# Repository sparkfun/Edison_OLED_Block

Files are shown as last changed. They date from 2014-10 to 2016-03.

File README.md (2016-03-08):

SparkFun Edison OLED Block
===========================

SparkFun Edison OLED Block

[*SparkFun Edison OLED Block(DEV-13035)*](https://www.sparkfun.com/products/13035)

Equip your Edison with a graphic display using the Edison OLED board! This board features a 0.66", 64x48 pixel monochrome OLED.

To add some control over your Edison and the OLED, this board also includes a small joystick and a pair of push-buttons. Use them to create a game, file navigator, or more!

Repository Contents
-------------------
* **/Firmware** - Example Pong sketch to demonstrate OLED Functionality. 
* **/Hardware** - All Eagle design files (.brd, .sch)
* **/Production** - Test bed files and production panel files

Documentation
--------------
* **[Hookup Guide](https://learn.sparkfun.com/tutorials/sparkfun-blocks-for-intel-edison---oled-block)** - Basic hookup guide for the OLED Block.
* **[SparkFun Fritzing repo](https://github.com/sparkfun/Fritzing_Parts)** - Fritzing diagrams for SparkFun products.
* **[SparkFun 3D Model repo](https://github.com/sparkfun/3D_Models)** - 3D models of SparkFun products. 
* **[SparkFun Graphical Datasheets](https://github.com/sparkfun/Graphical_Datasheets)** -Graphical Datasheets for various SparkFun products.

License Information
-------------------

This product is _**open source**_! 

Please review the LICENSE.md file for license information. 

If you have any questions or concerns on licensing, please contact techsupport@sparkfun.com.

Distributed as-is; no warranty is given.

- Your friends at SparkFun.

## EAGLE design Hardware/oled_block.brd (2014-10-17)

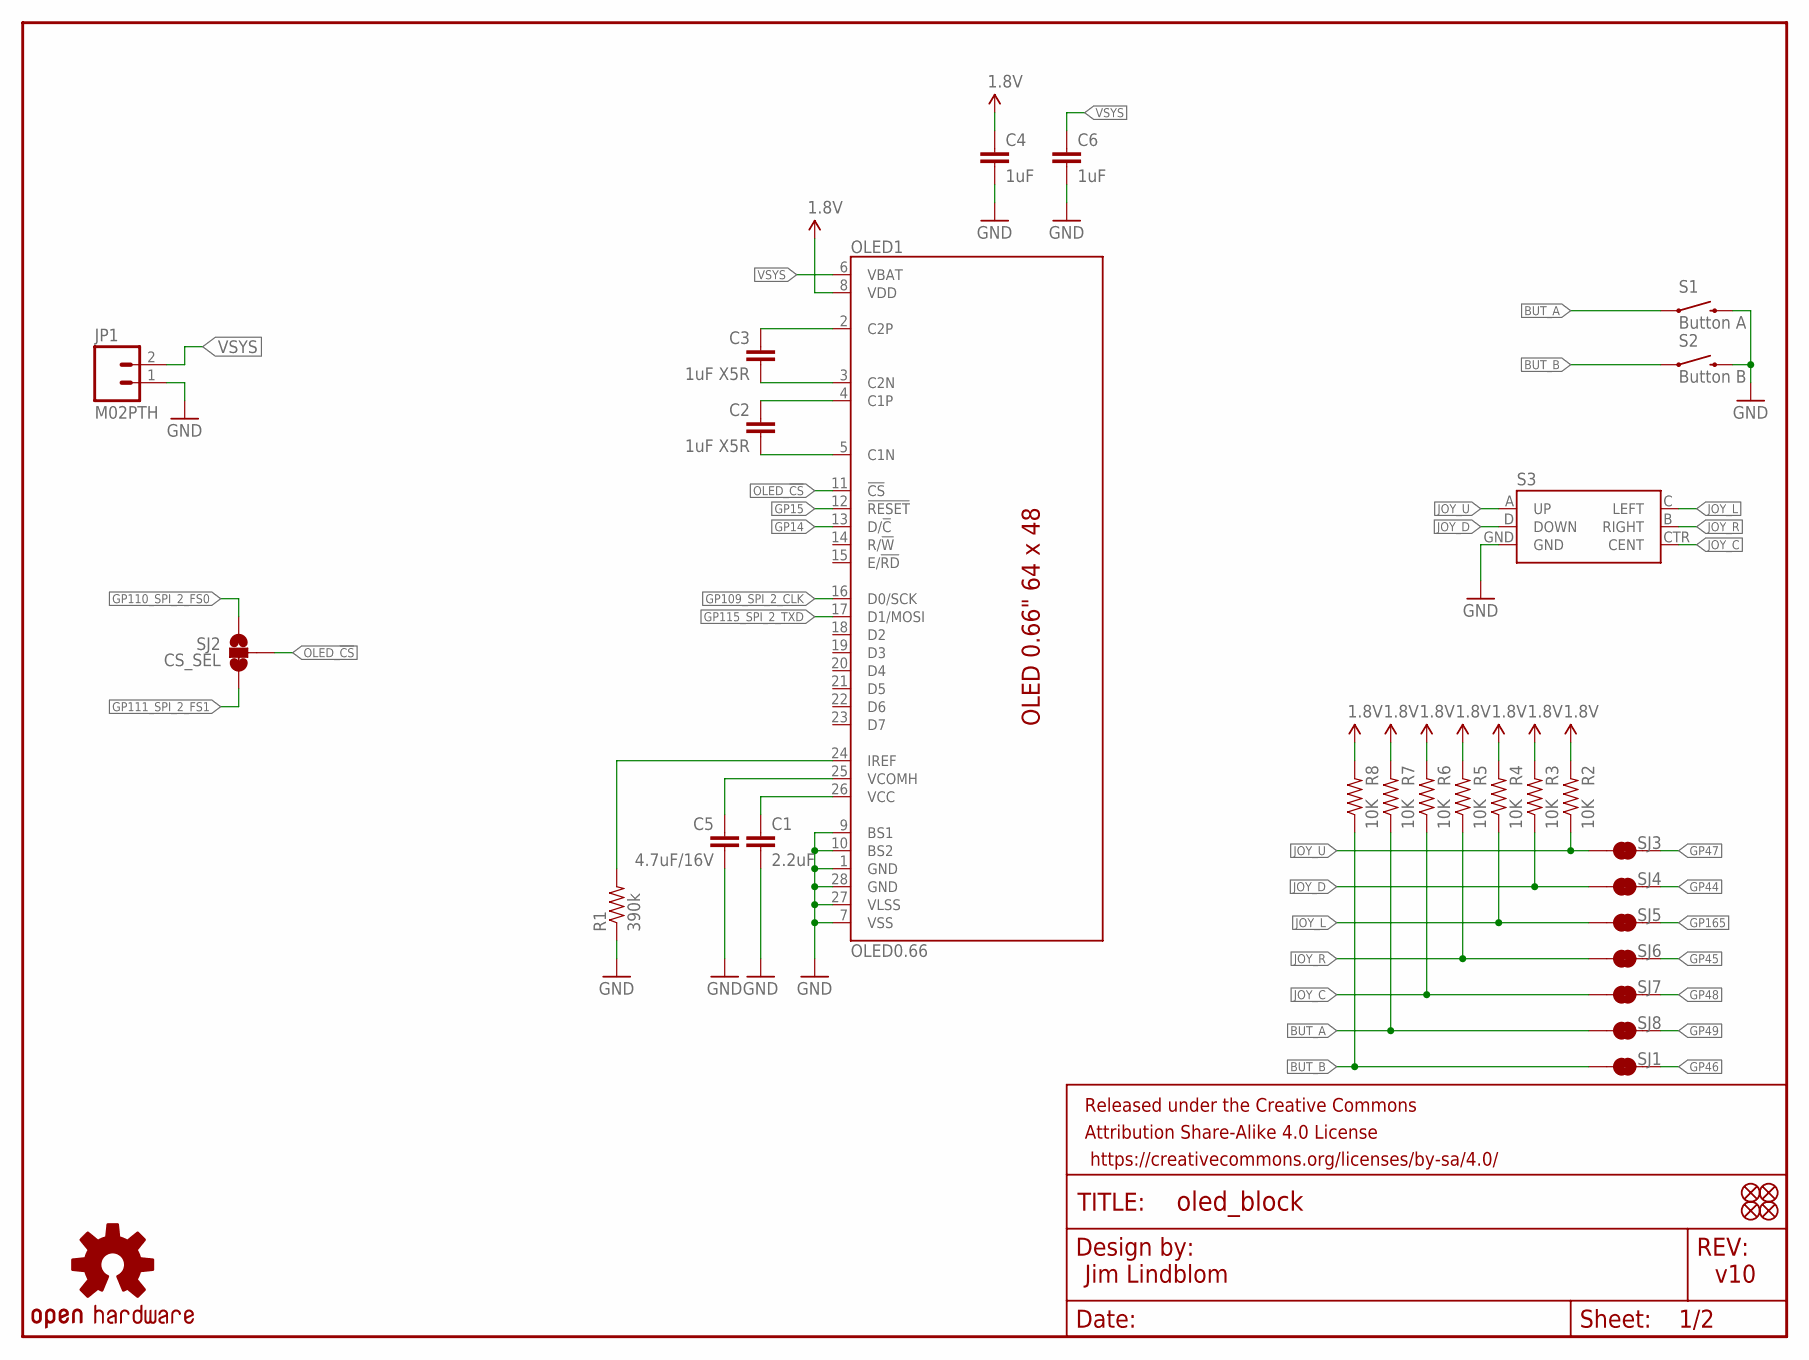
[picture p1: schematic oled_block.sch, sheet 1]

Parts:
C1: 2.2uF; 0805
C2, C3: 1uF X5R; 0805
C4, C6: 1uF; 0603-CAP
C5: 4.7uF/16V; 1206
FID1, FID2, FID3, FID4: FIDUCIAL1X2; FIDUCIAL-1X2
FRAME1: FRAME-LETTER; CREATIVE_COMMONS
JP1: M02PTH; 1X02
LOGO2: OSHW-LOGOS; OSHW-LOGO-S
OLED1: OLED0.66; OLED-0.66-64X48
R1: 390k; 0603-RES
R2, R3, R4, R5, R6, R7, R8: 10K; 0603-RES
S1: Button A; TACTILE_SWITCH_TALL
S2: Button B; TACTILE_SWITCH_TALL
S3: JOYSTICK_MINI
SJ1, SJ3, SJ4, SJ5, SJ6, SJ7, SJ8: JUMPER-PAD-2-NC_BY_TRACE; PAD-JUMPER-2-NC_BY_TRACE_YES_SILK
SJ2: CS_SEL; PAD-JUMPER-3-2OF3_NC_BY_TRACE_YES_SILK_FULL_BOX

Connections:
1.8V: C4.1, OLED1.8 (VDD), R2.2, R3.2, R4.2, R5.2, R6.2, R7.2, R8.2; also elsewhere on the board
BUT_A: R7.1, S1.A2 (1), SJ8.1
BUT_B: R8.1, S2.A2 (1), SJ1.1
C1N: C2.2, OLED1.5 (C1N)
C1P: C2.1, OLED1.4 (C1P)
C2N: C3.2, OLED1.3 (C2N)
C2P: C3.1, OLED1.2 (C2P)
GND: C1.2, C4.2, C5.2, C6.2, JP1.1, OLED1.1 (GND), OLED1.7 (VSS), OLED1.9 (BS1), OLED1.10 (BS2), OLED1.27 (VLSS), OLED1.28 (GND), R1.1, S1.B2 (2), S2.B2 (2), S3.GND; also elsewhere on the board
GP14: OLED1.13 (D/!C!); also elsewhere on the board
GP15: OLED1.12 (!RESET!); also elsewhere on the board
GP44: SJ4.2; also elsewhere on the board
GP45: SJ6.2; also elsewhere on the board
GP46: SJ1.2; also elsewhere on the board
GP47: SJ3.2; also elsewhere on the board
GP48: SJ7.2; also elsewhere on the board
GP49: SJ8.2; also elsewhere on the board
GP109_SPI_2_CLK: OLED1.16 (D0/SCK); also elsewhere on the board
GP110_SPI_2_FS0: SJ2.1; also elsewhere on the board
GP111_SPI_2_FS1: SJ2.3; also elsewhere on the board
GP115_SPI_2_TXD: OLED1.17 (D1/MOSI); also elsewhere on the board
GP165: SJ5.2; also elsewhere on the board
IREF: OLED1.24 (IREF), R1.2
JOY_C: R6.1, S3.CTR (CENT), SJ7.1
JOY_D: R3.1, S3.D (DOWN), SJ4.1
JOY_L: R4.1, S3.C (LEFT), SJ5.1
JOY_R: R5.1, S3.B (RIGHT), SJ6.1
JOY_U: R2.1, S3.A (UP), SJ3.1
OLED_!CS!: OLED1.11 (!CS!), SJ2.2
VCC: C1.1, OLED1.26 (VCC)
VCOMH: C5.1, OLED1.25 (VCOMH)
VSYS: C6.1, JP1.2, OLED1.6 (VBAT); also elsewhere on the board

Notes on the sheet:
Jim Lindblom
v10

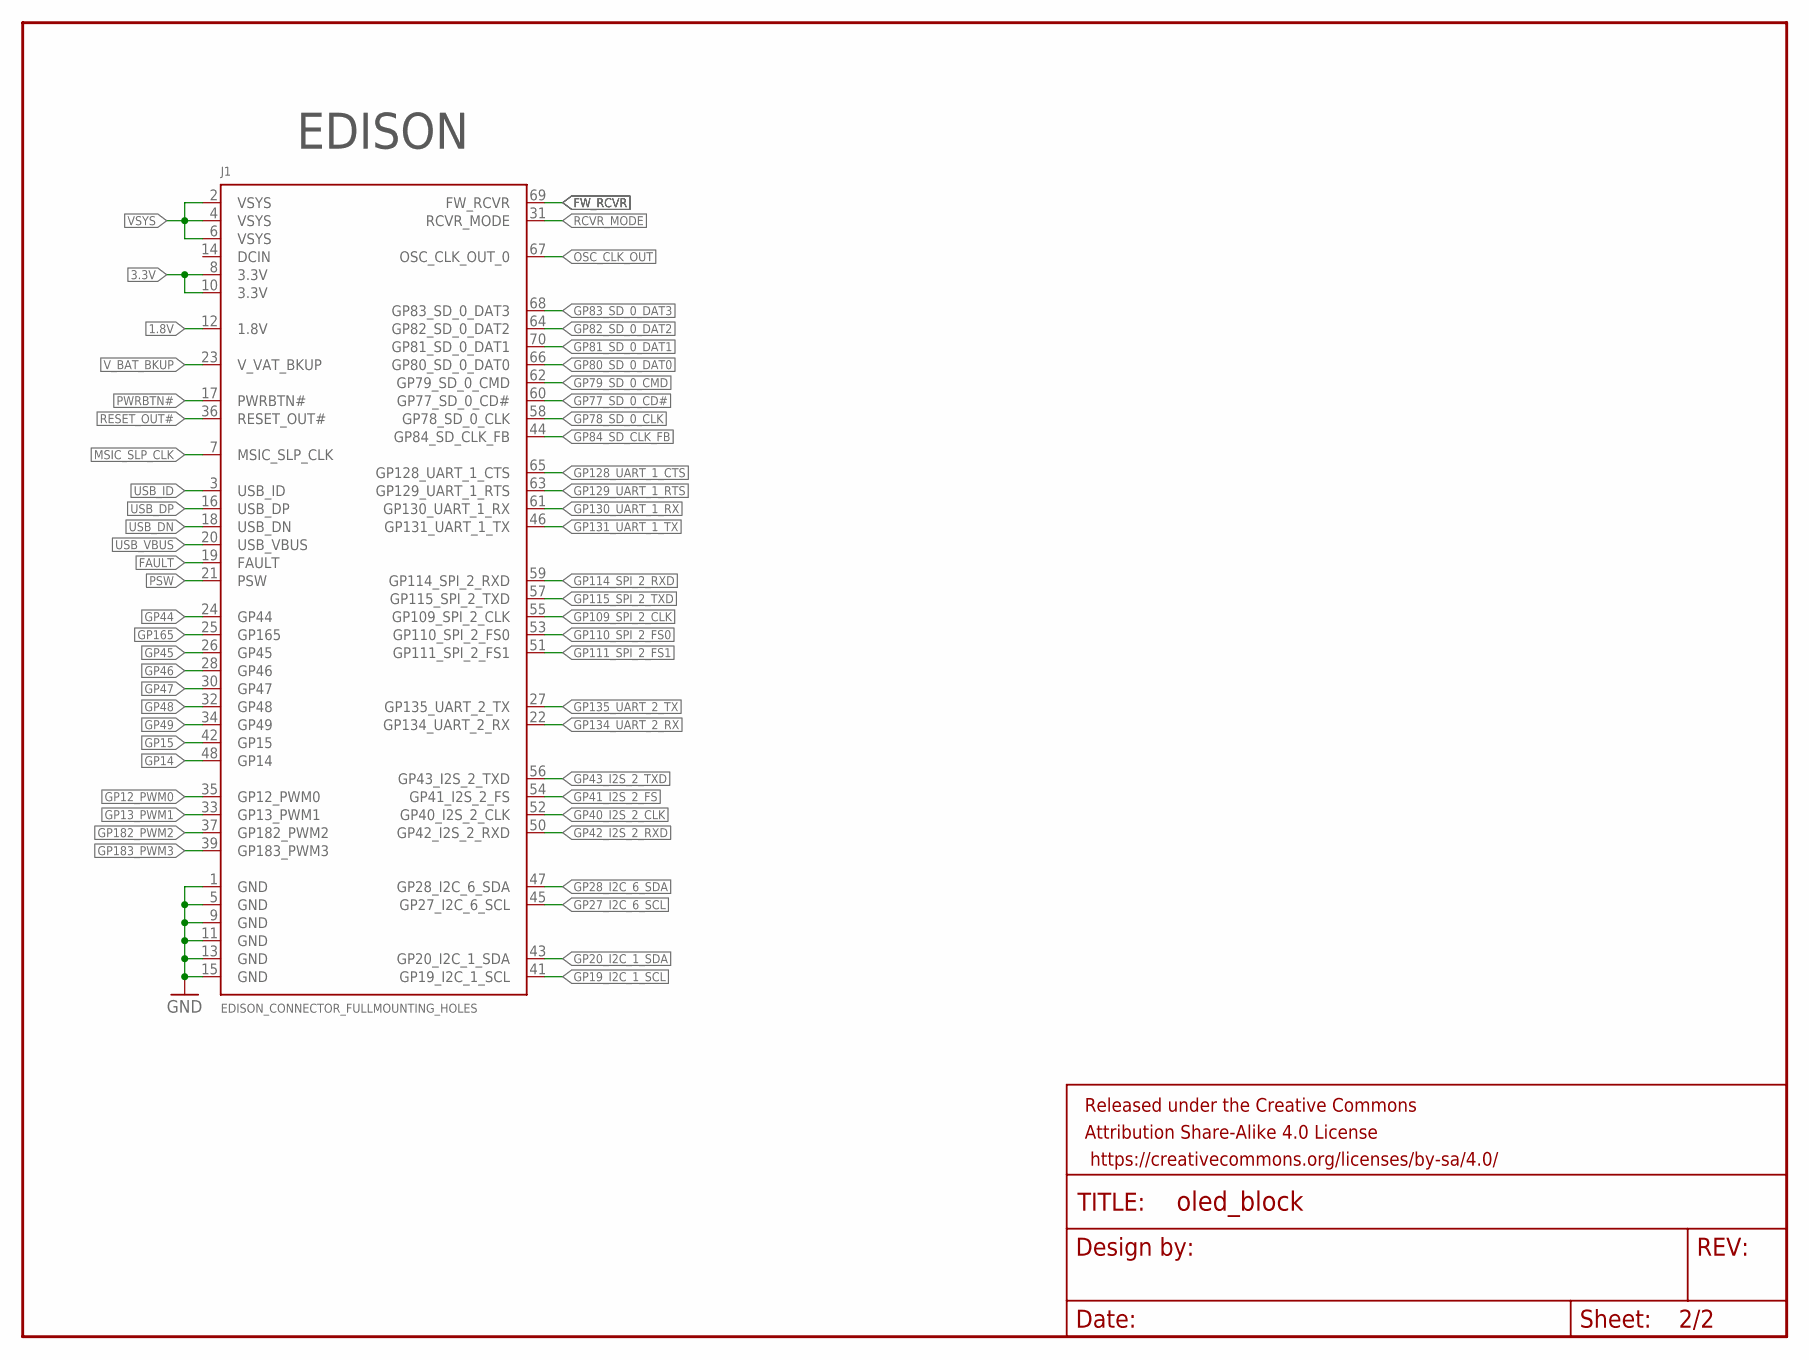
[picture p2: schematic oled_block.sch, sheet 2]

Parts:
FRAME2: FRAME-LETTER; CREATIVE_COMMONS
J1: EDISON_CONNECTOR_FULLMOUNTING_HOLES; EDISON_DAUGHTER

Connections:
1.8V: J1.12 (1.8V); also elsewhere on the board
3.3V: J1.8 (3.3V), J1.10 (3.3V)
FAULT: J1.19 (FAULT)
FW_RCVR: J1.69 (FW_RCVR)
GND: J1.1 (GND), J1.5 (GND), J1.9 (GND), J1.11 (GND), J1.13 (GND), J1.15 (GND); also elsewhere on the board
GP12_PWM0: J1.35 (GP12_PWM0)
GP13_PWM1: J1.33 (GP13_PWM1)
GP14: J1.48 (GP14); also elsewhere on the board
GP15: J1.42 (GP15); also elsewhere on the board
GP19_I2C_1_SCL: J1.41 (GP19_I2C_1_SCL)
GP20_I2C_1_SDA: J1.43 (GP20_I2C_1_SDA)
GP27_I2C_6_SCL: J1.45 (GP27_I2C_6_SCL)
GP28_I2C_6_SDA: J1.47 (GP28_I2C_6_SDA)
GP40_I2S_2_CLK: J1.52 (GP40_I2S_2_CLK)
GP41_I2S_2_FS: J1.54 (GP41_I2S_2_FS)
GP42_I2S_2_RXD: J1.50 (GP42_I2S_2_RXD)
GP43_I2S_2_TXD: J1.56 (GP43_I2S_2_TXD)
GP44: J1.24 (GP44); also elsewhere on the board
GP45: J1.26 (GP45); also elsewhere on the board
GP46: J1.28 (GP46); also elsewhere on the board
GP47: J1.30 (GP47); also elsewhere on the board
GP48: J1.32 (GP48); also elsewhere on the board
GP49: J1.34 (GP49); also elsewhere on the board
GP77_SD_0_CD#: J1.60 (GP77_SD_0_CD#)
GP78_SD_0_CLK: J1.58 (GP78_SD_0_CLK)
GP79_SD_0_CMD: J1.62 (GP79_SD_0_CMD)
GP80_SD_0_DAT0: J1.66 (GP80_SD_0_DAT0)
GP81_SD_0_DAT1: J1.70 (GP81_SD_0_DAT1)
GP82_SD_0_DAT2: J1.64 (GP82_SD_0_DAT2)
GP83_SD_0_DAT3: J1.68 (GP83_SD_0_DAT3)
GP84_SD_CLK_FB: J1.44 (GP84_SD_CLK_FB)
GP109_SPI_2_CLK: J1.55 (GP109_SPI_2_CLK); also elsewhere on the board
GP110_SPI_2_FS0: J1.53 (GP110_SPI_2_FS0); also elsewhere on the board
GP111_SPI_2_FS1: J1.51 (GP111_SPI_2_FS1); also elsewhere on the board
GP114_SPI_2_RXD: J1.59 (GP114_SPI_2_RXD)
GP115_SPI_2_TXD: J1.57 (GP115_SPI_2_TXD); also elsewhere on the board
GP128_UART_1_CTS: J1.65 (GP128_UART_1_CTS)
GP129_UART_1_RTS: J1.63 (GP129_UART_1_RTS)
GP130_UART_1_RX: J1.61 (GP130_UART_1_RX)
GP131_UART_1_TX: J1.46 (GP131_UART_1_TX)
GP134_UART_2_RX: J1.22 (GP134_UART_2_RX)
GP135_UART_2_TX: J1.27 (GP135_UART_2_TX)
GP165: J1.25 (GP165); also elsewhere on the board
GP182_PWM2: J1.37 (GP182_PWM2)
GP183_PWM3: J1.39 (GP183_PWM3)
MSIC_SLP_CLK: J1.7 (MSIC_SLP_CLK)
OSC_CLK_OUT: J1.67 (OSC_CLK_OUT_0)
PSW: J1.21 (PSW)
PWRBTN#: J1.17 (PWRBTN#)
RCVR_MODE: J1.31 (RCVR_MODE)
RESET_OUT#: J1.36 (RESET_OUT#)
USB_DN: J1.18 (USB_DN)
USB_DP: J1.16 (USB_DP)
USB_ID: J1.3 (USB_ID)
USB_VBUS: J1.20 (USB_VBUS)
VSYS: J1.2 (VSYS), J1.4 (VSYS), J1.6 (VSYS); also elsewhere on the board
V_BAT_BKUP: J1.23 (V_VAT_BKUP)

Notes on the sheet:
EDISON

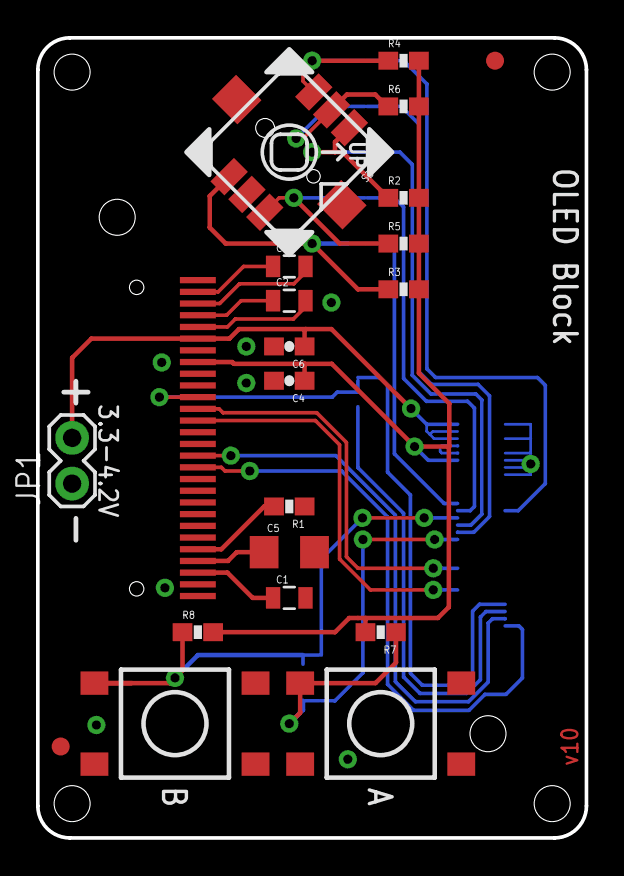
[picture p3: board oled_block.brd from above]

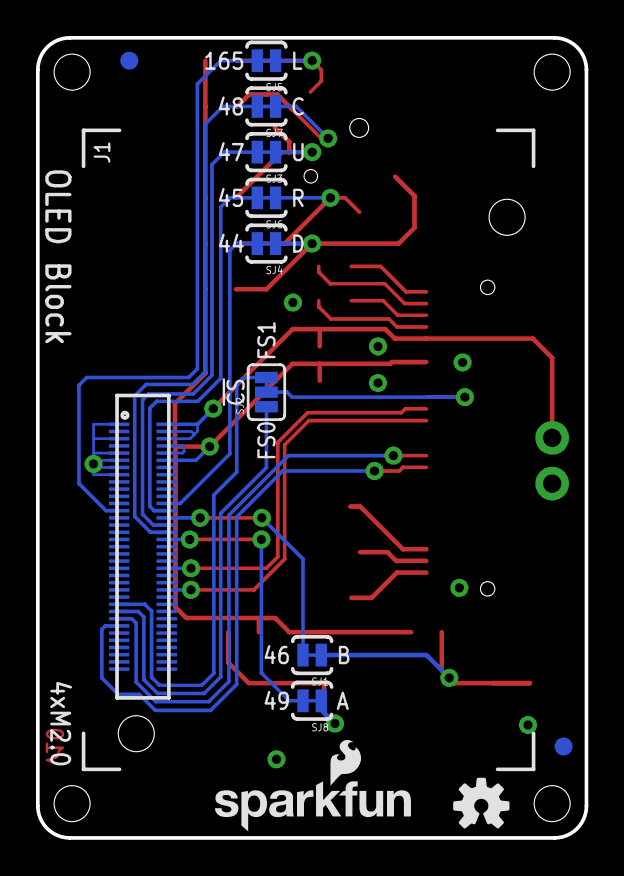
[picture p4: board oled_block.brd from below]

Board: 2 copper layers, 30.5 x 44.5 mm, 36 parts (13 on the bottom side), 32 nets.

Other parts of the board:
LOGO3: SFE_LOGO_NAME_FLAME.1_INCH; SFE_LOGO_NAME_FLAME_.1

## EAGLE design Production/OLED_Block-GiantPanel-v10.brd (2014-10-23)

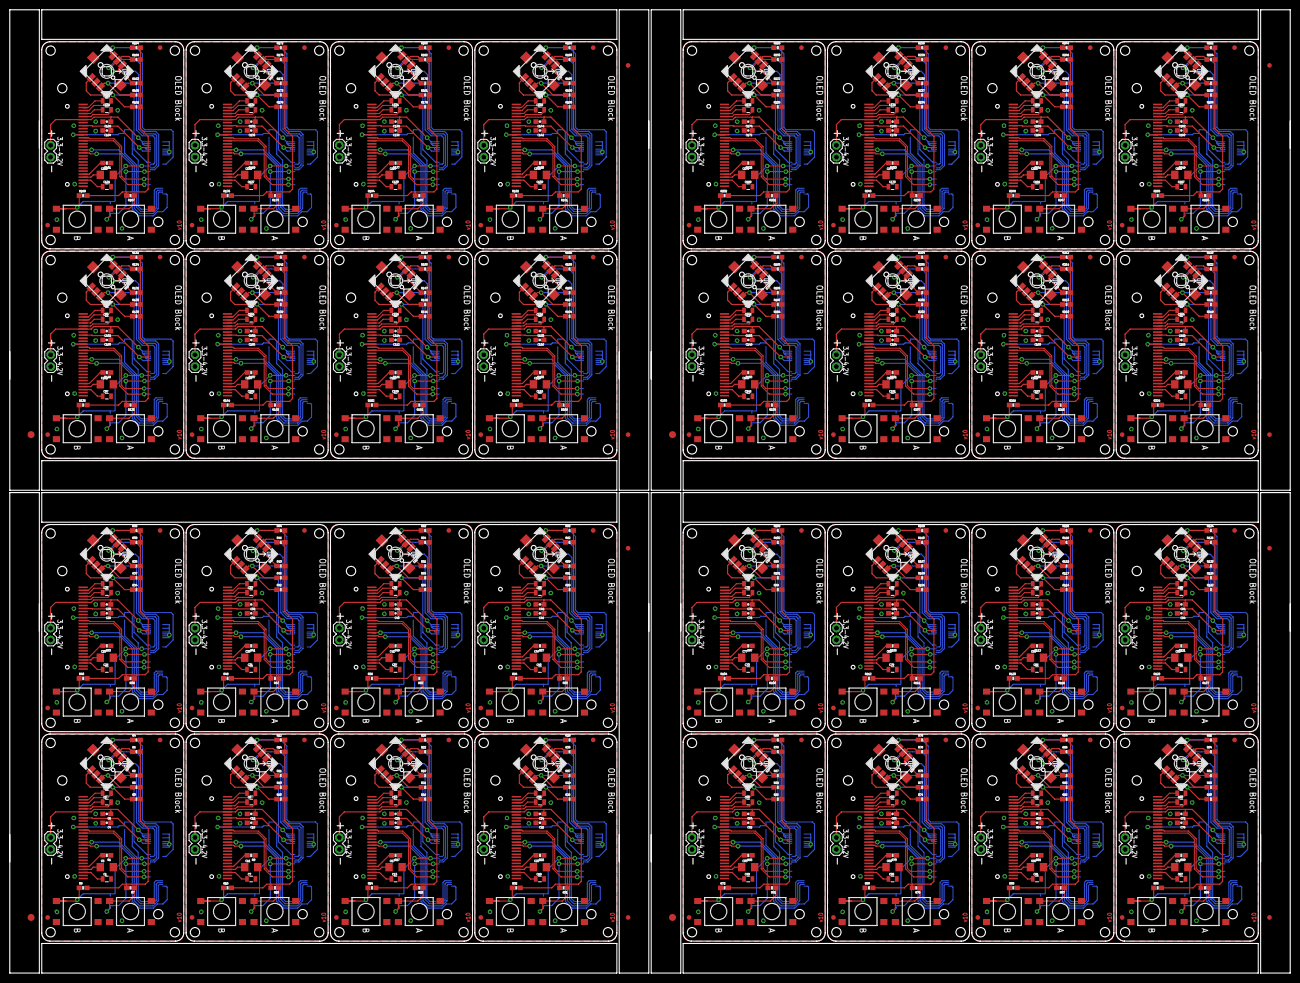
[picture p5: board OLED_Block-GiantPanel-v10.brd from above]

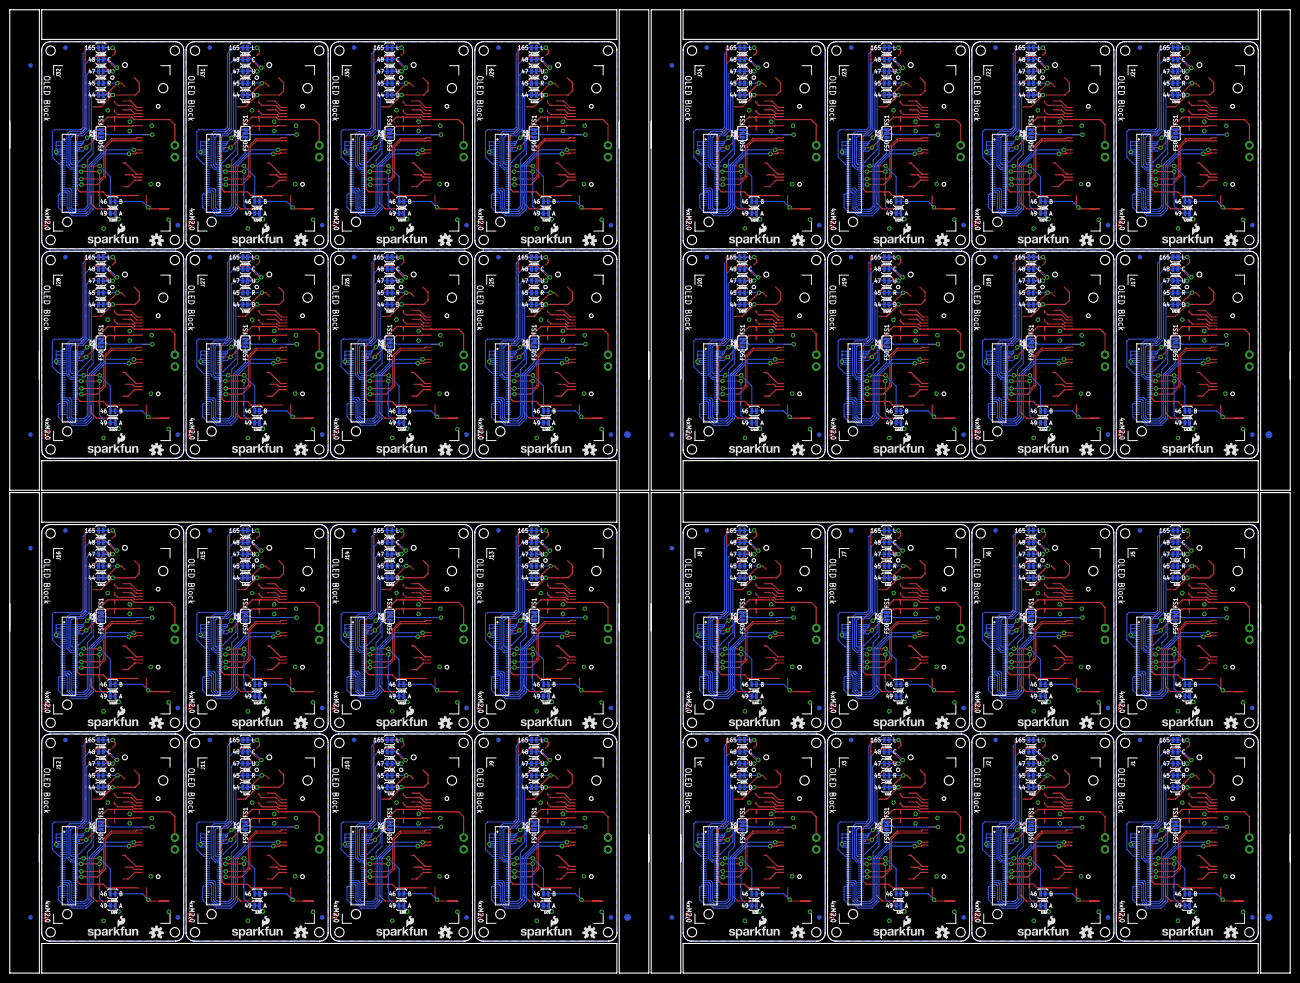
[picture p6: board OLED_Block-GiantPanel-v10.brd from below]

Board: 2 copper layers, 274.8 x 206.8 mm, 1112 parts (428 on the bottom side), 1024 nets.

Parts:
C1, C7, C13, C19, C25, C31, C37, C43, C49, C55, C61, C67, C73, C79, C85, C91, C97, C103, C109, C115, C121, C127, C133, C139, C145, C151, C157, C163, C169, C175, C181, C187: 2.2uF; 0805
C2, C3, C8, C9, C14, C15, C20, C21, C26, C27, C32, C33, C38, C39, C44, C45, C50, C51, C56, C57, C62, C63, C68, C69, C74, C75, C80, C81, C86, C87, C92, C93, C98, C99, C104, C105, C110, C111, C116, C117, C122, C123, C128, C129, C134, C135, C140, C141, C146, C147, C152, C153, C158, C159, C164, C165, C170, C171, C176, C177, C182, C183, C188, C189: 1uF X5R; 0805
C4, C6, C10, C12, C16, C18, C22, C24, C28, C30, C34, C36, C40, C42, C46, C48, C52, C54, C58, C60, C64, C66, C70, C72, C76, C78, C82, C84, C88, C90, C94, C96, C100, C102, C106, C108, C112, C114, C118, C120, C124, C126, C130, C132, C136, C138, C142, C144, C148, C150, C154, C156, C160, C162, C166, C168, C172, C174, C178, C180, C184, C186, C190, C192: 1uF; 0603-CAP
C5, C11, C17, C23, C29, C35, C41, C47, C53, C59, C65, C71, C77, C83, C89, C95, C101, C107, C113, C119, C125, C131, C137, C143, C149, C155, C161, C167, C173, C179, C185, C191: 4.7uF/16V; 1206
E$1, E$2, E$9, E$10, E$15, E$16, E$21, E$22: FIDUCIAL-1.5X3
E$3, E$4, E$5, E$6, E$7, E$8, E$11, E$12, E$13, E$14, E$17, E$18, E$19, E$20, E$23, E$24: FIDUCIAL-1X2
FID1, FID2, FID3, FID4, FID5, FID6, FID7, FID8, FID9, FID10, FID11, FID12, FID13, FID14, FID15, FID16, FID17, FID18, FID19, FID20, FID21, FID22, FID23, FID24, FID25, FID26, FID27, FID28, FID29, FID30, FID31, FID32, FID33, FID34, FID35, FID36, FID37, FID38, FID39, FID40, FID41, FID42, FID43, FID44, FID45, FID46, FID47, FID48, FID49, FID50, FID51, FID52, FID53, FID54, FID55, FID56, FID57, FID58, FID59, FID60, FID61, FID62, FID63, FID64, FID65, FID66, FID67, FID68, FID69, FID70, FID71, FID72, FID73, FID74, FID75, FID76, FID77, FID78, FID79, FID80, FID81, FID82, FID83, FID84, FID85, FID86, FID87, FID88, FID89, FID90, FID91, FID92, FID93, FID94, FID95, FID96, FID97, FID98, FID99, FID100, FID101, FID102, FID103, FID104, FID105, FID106, FID107, FID108, FID109, FID110, FID111, FID112, FID113, FID114, FID115, FID116, FID117, FID118, FID119, FID120, FID121, FID122, FID123, FID124, FID125, FID126, FID127, FID128: FIDUCIAL1X2; FIDUCIAL-1X2
J1, J2, J3, J4, J5, J6, J7, J8, J9, J10, J11, J12, J13, J14, J15, J16, J17, J18, J19, J20, J21, J22, J23, J24, J25, J26, J27, J28, J29, J30, J31, J32: EDISON_CONNECTOR_FULLMOUNTING_HOLES; EDISON_DAUGHTER
JP1, JP2, JP3, JP4, JP5, JP6, JP7, JP8, JP9, JP10, JP11, JP12, JP13, JP14, JP15, JP16, JP17, JP18, JP19, JP20, JP21, JP22, JP23, JP24, JP25, JP26, JP27, JP28, JP29, JP30, JP31, JP32: M02PTH; 1X02
LOGO1, LOGO2, LOGO5, LOGO7, LOGO9, LOGO11, LOGO13, LOGO15, LOGO17, LOGO19, LOGO21, LOGO23, LOGO25, LOGO27, LOGO29, LOGO31, LOGO33, LOGO35, LOGO37, LOGO39, LOGO41, LOGO43, LOGO45, LOGO47, LOGO49, LOGO51, LOGO53, LOGO55, LOGO57, LOGO59, LOGO61, LOGO63: OSHW-LOGOS; OSHW-LOGO-S
LOGO3, LOGO4, LOGO6, LOGO8, LOGO10, LOGO12, LOGO14, LOGO16, LOGO18, LOGO20, LOGO22, LOGO24, LOGO26, LOGO28, LOGO30, LOGO32, LOGO34, LOGO36, LOGO38, LOGO40, LOGO42, LOGO44, LOGO46, LOGO48, LOGO50, LOGO52, LOGO54, LOGO56, LOGO58, LOGO60, LOGO62, LOGO64: SFE_LOGO_NAME_FLAME.1_INCH; SFE_LOGO_NAME_FLAME_.1
OLED1, OLED2, OLED3, OLED4, OLED5, OLED6, OLED7, OLED8, OLED9, OLED10, OLED11, OLED12, OLED13, OLED14, OLED15, OLED16, OLED17, OLED18, OLED19, OLED20, OLED21, OLED22, OLED23, OLED24, OLED25, OLED26, OLED27, OLED28, OLED29, OLED30, OLED31, OLED32: OLED0.66; OLED-0.66-64X48
R1, R9, R17, R25, R33, R41, R49, R57, R65, R73, R81, R89, R97, R105, R113, R121, R129, R137, R145, R153, R161, R169, R177, R185, R193, R201, R209, R217, R225, R233, R241, R249: 390k; 0603-RES
R2, R3, R4, R5, R6, R7, R8, R10, R11, R12, R13, R14, R15, R16, R18, R19, R20, R21, R22, R23, R24, R26, R27, R28, R29, R30, R31, R32, R34, R35, R36, R37, R38, R39, R40, R42, R43, R44, R45, R46, R47, R48, R50, R51, R52, R53, R54, R55, R56, R58, R59, R60, R61, R62, R63, R64, R66, R67, R68, R69, R70, R71, R72, R74, R75, R76, R77, R78, R79, R80, R82, R83, R84, R85, R86, R87, R88, R90, R91, R92, R93, R94, R95, R96, R98, R99, R100, R101, R102, R103, R104, R106, R107, R108, R109, R110, R111, R112, R114, R115, R116, R117, R118, R119, R120, R122, R123, R124, R125, R126, R127, R128, R130, R131, R132, R133, R134, R135, R136, R138, R139, R140, R141, R142, R143, R144, R146, R147, R148, R149, R150, R151, R152, R154, R155, R156, R157, R158, R159, R160, R162, R163, R164, R165, R166, R167, R168, R170, R171, R172, R173, R174, R175, R176, R178, R179, R180, R181, R182, R183, R184, R186, R187, R188, R189, R190, R191, R192, R194, R195, R196, R197, R198, R199, R200, R202, R203, R204, R205, R206, R207, R208, R210, R211, R212, R213, R214, R215, R216, R218, R219, R220, R221, R222, R223, R224, R226, R227, R228, R229, R230, R231, R232, R234, R235, R236, R237, R238, R239, R240, R242, R243, R244, R245, R246, R247, R248, R250, R251, R252, R253, R254, R255, R256: 10K; 0603-RES
S1, S4, S7, S10, S13, S16, S19, S22, S25, S28, S31, S34, S37, S40, S43, S46, S49, S52, S55, S58, S61, S64, S67, S70, S73, S76, S79, S82, S85, S88, S91, S94: Button A; TACTILE_SWITCH_TALL
S2, S5, S8, S11, S14, S17, S20, S23, S26, S29, S32, S35, S38, S41, S44, S47, S50, S53, S56, S59, S62, S65, S68, S71, S74, S77, S80, S83, S86, S89, S92, S95: Button B; TACTILE_SWITCH_TALL
S3, S6, S9, S12, S15, S18, S21, S24, S27, S30, S33, S36, S39, S42, S45, S48, S51, S54, S57, S60, S63, S66, S69, S72, S75, S78, S81, S84, S87, S90, S93, S96: JOYSTICK_MINI
SJ1, SJ3, SJ4, SJ5, SJ6, SJ7, SJ8, SJ10, SJ11, SJ12, SJ13, SJ14, SJ15, SJ16, SJ18, SJ19, SJ20, SJ21, SJ22, SJ23, SJ24, SJ26, SJ27, SJ28, SJ29, SJ30, SJ31, SJ32, SJ34, SJ35, SJ36, SJ37, SJ38, SJ39, SJ40, SJ42, SJ43, SJ44, SJ45, SJ46, SJ47, SJ48, SJ50, SJ51, SJ52, SJ53, SJ54, SJ55, SJ56, SJ58, SJ59, SJ60, SJ61, SJ62, SJ63, SJ64, SJ66, SJ67, SJ68, SJ69, SJ70, SJ71, SJ72, SJ74, SJ75, SJ76, SJ77, SJ78, SJ79, SJ80, SJ82, SJ83, SJ84, SJ85, SJ86, SJ87, SJ88, SJ90, SJ91, SJ92, SJ93, SJ94, SJ95, SJ96, SJ98, SJ99, SJ100, SJ101, SJ102, SJ103, SJ104, SJ106, SJ107, SJ108, SJ109, SJ110, SJ111, SJ112, SJ114, SJ115, SJ116, SJ117, SJ118, SJ119, SJ120, SJ122, SJ123, SJ124, SJ125, SJ126, SJ127, SJ128, SJ130, SJ131, SJ132, SJ133, SJ134, SJ135, SJ136, SJ138, SJ139, SJ140, SJ141, SJ142, SJ143, SJ144, SJ146, SJ147, SJ148, SJ149, SJ150, SJ151, SJ152, SJ154, SJ155, SJ156, SJ157, SJ158, SJ159, SJ160, SJ162, SJ163, SJ164, SJ165, SJ166, SJ167, SJ168, SJ170, SJ171, SJ172, SJ173, SJ174, SJ175, SJ176, SJ178, SJ179, SJ180, SJ181, SJ182, SJ183, SJ184, SJ186, SJ187, SJ188, SJ189, SJ190, SJ191, SJ192, SJ194, SJ195, SJ196, SJ197, SJ198, SJ199, SJ200, SJ202, SJ203, SJ204, SJ205, SJ206, SJ207, SJ208, SJ210, SJ211, SJ212, SJ213, SJ214, SJ215, SJ216, SJ218, SJ219, SJ220, SJ221, SJ222, SJ223, SJ224, SJ226, SJ227, SJ228, SJ229, SJ230, SJ231, SJ232, SJ234, SJ235, SJ236, SJ237, SJ238, SJ239, SJ240, SJ242, SJ243, SJ244, SJ245, SJ246, SJ247, SJ248, SJ250, SJ251, SJ252, SJ253, SJ254, SJ255, SJ256: PAD-JUMPER-2-NC_BY_TRACE_YES_SILK
SJ2, SJ9, SJ17, SJ25, SJ33, SJ41, SJ49, SJ57, SJ65, SJ73, SJ81, SJ89, SJ97, SJ105, SJ113, SJ121, SJ129, SJ137, SJ145, SJ153, SJ161, SJ169, SJ177, SJ185, SJ193, SJ201, SJ209, SJ217, SJ225, SJ233, SJ241, SJ249: CS_SEL; PAD-JUMPER-3-2OF3_NC_BY_TRACE_YES_SILK_FULL_BOX

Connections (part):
1.8V: C4.1, J1.12, OLED1.8, R2.2, R3.2, R4.2, R5.2, R6.2, R7.2, R8.2
1.8V1: C10.1, J2.12, OLED2.8, R10.2, R11.2, R12.2, R13.2, R14.2, R15.2, R16.2
1.8V2: C16.1, J3.12, OLED3.8, R18.2, R19.2, R20.2, R21.2, R22.2, R23.2, R24.2
1.8V3: C22.1, J4.12, OLED4.8, R26.2, R27.2, R28.2, R29.2, R30.2, R31.2, R32.2
1.8V4: C28.1, J5.12, OLED5.8, R34.2, R35.2, R36.2, R37.2, R38.2, R39.2, R40.2
1.8V5: C34.1, J6.12, OLED6.8, R42.2, R43.2, R44.2, R45.2, R46.2, R47.2, R48.2
1.8V6: C40.1, J7.12, OLED7.8, R50.2, R51.2, R52.2, R53.2, R54.2, R55.2, R56.2
1.8V7: C46.1, J8.12, OLED8.8, R58.2, R59.2, R60.2, R61.2, R62.2, R63.2, R64.2
1.8V8: C52.1, J9.12, OLED9.8, R66.2, R67.2, R68.2, R69.2, R70.2, R71.2, R72.2
1.8V9: C58.1, J10.12, OLED10.8, R74.2, R75.2, R76.2, R77.2, R78.2, R79.2, R80.2
1.8V10: C64.1, J11.12, OLED11.8, R82.2, R83.2, R84.2, R85.2, R86.2, R87.2, R88.2
1.8V11: C70.1, J12.12, OLED12.8, R90.2, R91.2, R92.2, R93.2, R94.2, R95.2, R96.2
1.8V12: C76.1, J13.12, OLED13.8, R98.2, R99.2, R100.2, R101.2, R102.2, R103.2, R104.2
1.8V13: C82.1, J14.12, OLED14.8, R106.2, R107.2, R108.2, R109.2, R110.2, R111.2, R112.2
1.8V14: C88.1, J15.12, OLED15.8, R114.2, R115.2, R116.2, R117.2, R118.2, R119.2, R120.2
1.8V15: C94.1, J16.12, OLED16.8, R122.2, R123.2, R124.2, R125.2, R126.2, R127.2, R128.2
1.8V16: C100.1, J17.12, OLED17.8, R130.2, R131.2, R132.2, R133.2, R134.2, R135.2, R136.2
1.8V17: C106.1, J18.12, OLED18.8, R138.2, R139.2, R140.2, R141.2, R142.2, R143.2, R144.2
1.8V18: C112.1, J19.12, OLED19.8, R146.2, R147.2, R148.2, R149.2, R150.2, R151.2, R152.2
1.8V19: C118.1, J20.12, OLED20.8, R154.2, R155.2, R156.2, R157.2, R158.2, R159.2, R160.2
1.8V20: C124.1, J21.12, OLED21.8, R162.2, R163.2, R164.2, R165.2, R166.2, R167.2, R168.2
1.8V21: C130.1, J22.12, OLED22.8, R170.2, R171.2, R172.2, R173.2, R174.2, R175.2, R176.2
1.8V22: C136.1, J23.12, OLED23.8, R178.2, R179.2, R180.2, R181.2, R182.2, R183.2, R184.2
1.8V23: C142.1, J24.12, OLED24.8, R186.2, R187.2, R188.2, R189.2, R190.2, R191.2, R192.2
1.8V24: C148.1, J25.12, OLED25.8, R194.2, R195.2, R196.2, R197.2, R198.2, R199.2, R200.2
1.8V25: C154.1, J26.12, OLED26.8, R202.2, R203.2, R204.2, R205.2, R206.2, R207.2, R208.2
1.8V26: C160.1, J27.12, OLED27.8, R210.2, R211.2, R212.2, R213.2, R214.2, R215.2, R216.2
1.8V27: C166.1, J28.12, OLED28.8, R218.2, R219.2, R220.2, R221.2, R222.2, R223.2, R224.2
1.8V28: C172.1, J29.12, OLED29.8, R226.2, R227.2, R228.2, R229.2, R230.2, R231.2, R232.2
1.8V29: C178.1, J30.12, OLED30.8, R234.2, R235.2, R236.2, R237.2, R238.2, R239.2, R240.2
1.8V30: C184.1, J31.12, OLED31.8, R242.2, R243.2, R244.2, R245.2, R246.2, R247.2, R248.2
1.8V31: C190.1, J32.12, OLED32.8, R250.2, R251.2, R252.2, R253.2, R254.2, R255.2, R256.2
3.3V: J1.8, J1.10
3.3V1: J2.8, J2.10
3.3V2: J3.8, J3.10
3.3V3: J4.8, J4.10
3.3V4: J5.8, J5.10
3.3V5: J6.8, J6.10
3.3V6: J7.8, J7.10
3.3V7: J8.8, J8.10
3.3V8: J9.8, J9.10
3.3V9: J10.8, J10.10
3.3V10: J11.8, J11.10
3.3V11: J12.8, J12.10
3.3V12: J13.8, J13.10
3.3V13: J14.8, J14.10
3.3V14: J15.8, J15.10
3.3V15: J16.8, J16.10
3.3V16: J17.8, J17.10
3.3V17: J18.8, J18.10
3.3V18: J19.8, J19.10
3.3V19: J20.8, J20.10
3.3V20: J21.8, J21.10
3.3V21: J22.8, J22.10
3.3V22: J23.8, J23.10
3.3V23: J24.8, J24.10
3.3V24: J25.8, J25.10
3.3V25: J26.8, J26.10
3.3V26: J27.8, J27.10
3.3V27: J28.8, J28.10
3.3V28: J29.8, J29.10
3.3V29: J30.8, J30.10
3.3V30: J31.8, J31.10
3.3V31: J32.8, J32.10
BUT_A: R7.1, S1.A2, SJ8.1
BUT_A1: R15.1, S4.A2, SJ16.1
BUT_A2: R23.1, S7.A2, SJ24.1
BUT_A3: R31.1, S10.A2, SJ32.1
BUT_A4: R39.1, S13.A2, SJ40.1
BUT_A5: R47.1, S16.A2, SJ48.1
BUT_A6: R55.1, S19.A2, SJ56.1
BUT_A7: R63.1, S22.A2, SJ64.1
BUT_A8: R71.1, S25.A2, SJ72.1
BUT_A9: R79.1, S28.A2, SJ80.1
BUT_A10: R87.1, S31.A2, SJ88.1
BUT_A11: R95.1, S34.A2, SJ96.1
BUT_A12: R103.1, S37.A2, SJ104.1
BUT_A13: R111.1, S40.A2, SJ112.1
BUT_A14: R119.1, S43.A2, SJ120.1
BUT_A15: R127.1, S46.A2, SJ128.1
BUT_A16: R135.1, S49.A2, SJ136.1
BUT_A17: R143.1, S52.A2, SJ144.1
BUT_A18: R151.1, S55.A2, SJ152.1
BUT_A19: R159.1, S58.A2, SJ160.1
BUT_A20: R167.1, S61.A2, SJ168.1
BUT_A21: R175.1, S64.A2, SJ176.1
BUT_A22: R183.1, S67.A2, SJ184.1
BUT_A23: R191.1, S70.A2, SJ192.1
BUT_A24: R199.1, S73.A2, SJ200.1
BUT_A25: R207.1, S76.A2, SJ208.1
BUT_A26: R215.1, S79.A2, SJ216.1
BUT_A27: R223.1, S82.A2, SJ224.1
BUT_A28: R231.1, S85.A2, SJ232.1
BUT_A29: R239.1, S88.A2, SJ240.1
BUT_A30: R247.1, S91.A2, SJ248.1
BUT_A31: R255.1, S94.A2, SJ256.1
BUT_B: R8.1, S2.A2, SJ1.1
BUT_B1: R16.1, S5.A2, SJ10.1
BUT_B2: R24.1, S8.A2, SJ18.1
BUT_B3: R32.1, S11.A2, SJ26.1
BUT_B4: R40.1, S14.A2, SJ34.1
BUT_B5: R48.1, S17.A2, SJ42.1
BUT_B6: R56.1, S20.A2, SJ50.1
BUT_B7: R64.1, S23.A2, SJ58.1
BUT_B8: R72.1, S26.A2, SJ66.1
BUT_B9: R80.1, S29.A2, SJ74.1
BUT_B10: R88.1, S32.A2, SJ82.1
BUT_B11: R96.1, S35.A2, SJ90.1
BUT_B12: R104.1, S38.A2, SJ98.1
BUT_B13: R112.1, S41.A2, SJ106.1
BUT_B14: R120.1, S44.A2, SJ114.1
BUT_B15: R128.1, S47.A2, SJ122.1
BUT_B16: R136.1, S50.A2, SJ130.1
BUT_B17: R144.1, S53.A2, SJ138.1
BUT_B18: R152.1, S56.A2, SJ146.1
BUT_B19: R160.1, S59.A2, SJ154.1
BUT_B20: R168.1, S62.A2, SJ162.1
BUT_B21: R176.1, S65.A2, SJ170.1
BUT_B22: R184.1, S68.A2, SJ178.1
BUT_B23: R192.1, S71.A2, SJ186.1
BUT_B24: R200.1, S74.A2, SJ194.1
BUT_B25: R208.1, S77.A2, SJ202.1
BUT_B26: R216.1, S80.A2, SJ210.1
BUT_B27: R224.1, S83.A2, SJ218.1
BUT_B28: R232.1, S86.A2, SJ226.1
BUT_B29: R240.1, S89.A2, SJ234.1
BUT_B30: R248.1, S92.A2, SJ242.1
BUT_B31: R256.1, S95.A2, SJ250.1
C1N: C2.2, OLED1.5
C1N1: C8.2, OLED2.5
C1N2: C14.2, OLED3.5
C1N3: C20.2, OLED4.5
C1N4: C26.2, OLED5.5
C1N5: C32.2, OLED6.5
C1N6: C38.2, OLED7.5
C1N7: C44.2, OLED8.5
C1N8: C50.2, OLED9.5
C1N9: C56.2, OLED10.5
C1N10: C62.2, OLED11.5
C1N11: C68.2, OLED12.5
C1N12: C74.2, OLED13.5
C1N13: C80.2, OLED14.5
C1N14: C86.2, OLED15.5
C1N15: C92.2, OLED16.5
C1N16: C98.2, OLED17.5
C1N17: C104.2, OLED18.5
C1N18: C110.2, OLED19.5
C1N19: C116.2, OLED20.5
C1N20: C122.2, OLED21.5
C1N21: C128.2, OLED22.5
C1N22: C134.2, OLED23.5
C1N23: C140.2, OLED24.5
C1N24: C146.2, OLED25.5
C1N25: C152.2, OLED26.5
C1N26: C158.2, OLED27.5
C1N27: C164.2, OLED28.5
C1N28: C170.2, OLED29.5
C1N29: C176.2, OLED30.5
C1N30: C182.2, OLED31.5
C1N31: C188.2, OLED32.5
C1P: C2.1, OLED1.4
C1P1: C8.1, OLED2.4
C1P2: C14.1, OLED3.4
C1P3: C20.1, OLED4.4
C1P4: C26.1, OLED5.4
C1P5: C32.1, OLED6.4
C1P6: C38.1, OLED7.4
C1P7: C44.1, OLED8.4
C1P8: C50.1, OLED9.4
C1P9: C56.1, OLED10.4
C1P10: C62.1, OLED11.4
C1P11: C68.1, OLED12.4
C1P12: C74.1, OLED13.4
C1P13: C80.1, OLED14.4
C1P14: C86.1, OLED15.4
C1P15: C92.1, OLED16.4
C1P16: C98.1, OLED17.4
C1P17: C104.1, OLED18.4
C1P18: C110.1, OLED19.4
C1P19: C116.1, OLED20.4
C1P20: C122.1, OLED21.4
C1P21: C128.1, OLED22.4
C1P22: C134.1, OLED23.4
C1P23: C140.1, OLED24.4
C1P24: C146.1, OLED25.4
C1P25: C152.1, OLED26.4
C1P26: C158.1, OLED27.4
C1P27: C164.1, OLED28.4
C1P28: C170.1, OLED29.4
C1P29: C176.1, OLED30.4
C1P30: C182.1, OLED31.4
C1P31: C188.1, OLED32.4
C2N: C3.2, OLED1.3
C2N1: C9.2, OLED2.3
C2N2: C15.2, OLED3.3
C2N3: C21.2, OLED4.3
C2N4: C27.2, OLED5.3
C2N5: C33.2, OLED6.3
C2N6: C39.2, OLED7.3
C2N7: C45.2, OLED8.3
C2N8: C51.2, OLED9.3
C2N9: C57.2, OLED10.3
C2N10: C63.2, OLED11.3
C2N11: C69.2, OLED12.3
C2N12: C75.2, OLED13.3
C2N13: C81.2, OLED14.3
C2N14: C87.2, OLED15.3
C2N15: C93.2, OLED16.3
C2N16: C99.2, OLED17.3
C2N17: C105.2, OLED18.3
C2N18: C111.2, OLED19.3
C2N19: C117.2, OLED20.3
C2N20: C123.2, OLED21.3
C2N21: C129.2, OLED22.3
C2N22: C135.2, OLED23.3
C2N23: C141.2, OLED24.3
C2N24: C147.2, OLED25.3
C2N25: C153.2, OLED26.3
C2N26: C159.2, OLED27.3
C2N27: C165.2, OLED28.3
C2N28: C171.2, OLED29.3
C2N29: C177.2, OLED30.3
C2N30: C183.2, OLED31.3
C2N31: C189.2, OLED32.3
C2P: C3.1, OLED1.2
C2P1: C9.1, OLED2.2
C2P2: C15.1, OLED3.2
C2P3: C21.1, OLED4.2
C2P4: C27.1, OLED5.2
C2P5: C33.1, OLED6.2
C2P6: C39.1, OLED7.2
C2P7: C45.1, OLED8.2
C2P8: C51.1, OLED9.2
C2P9: C57.1, OLED10.2
C2P10: C63.1, OLED11.2
C2P11: C69.1, OLED12.2
C2P12: C75.1, OLED13.2
C2P13: C81.1, OLED14.2
C2P14: C87.1, OLED15.2
C2P15: C93.1, OLED16.2
C2P16: C99.1, OLED17.2
C2P17: C105.1, OLED18.2
C2P18: C111.1, OLED19.2
C2P19: C117.1, OLED20.2
C2P20: C123.1, OLED21.2
C2P21: C129.1, OLED22.2
C2P22: C135.1, OLED23.2
C2P23: C141.1, OLED24.2
C2P24: C147.1, OLED25.2
C2P25: C153.1, OLED26.2
C2P26: C159.1, OLED27.2
C2P27: C165.1, OLED28.2
C2P28: C171.1, OLED29.2
C2P29: C177.1, OLED30.2
C2P30: C183.1, OLED31.2
C2P31: C189.1, OLED32.2
GND: C1.2, C4.2, C5.2, C6.2, J1.1, J1.5, J1.9, J1.11, J1.13, J1.15, JP1.1, OLED1.1, OLED1.7, OLED1.9, OLED1.10, OLED1.27, OLED1.28, R1.1, S1.B2, S2.B2, S3.GND
GND1: C7.2, C10.2, C11.2, C12.2, J2.1, J2.5, J2.9, J2.11, J2.13, J2.15, JP2.1, OLED2.1, OLED2.7, OLED2.9, OLED2.10, OLED2.27, OLED2.28, R9.1, S4.B2, S5.B2, S6.GND
GND2: C13.2, C16.2, C17.2, C18.2, J3.1, J3.5, J3.9, J3.11, J3.13, J3.15, JP3.1, OLED3.1, OLED3.7, OLED3.9, OLED3.10, OLED3.27, OLED3.28, R17.1, S7.B2, S8.B2, S9.GND
GND3: C19.2, C22.2, C23.2, C24.2, J4.1, J4.5, J4.9, J4.11, J4.13, J4.15, JP4.1, OLED4.1, OLED4.7, OLED4.9, OLED4.10, OLED4.27, OLED4.28, R25.1, S10.B2, S11.B2, S12.GND
GND4: C25.2, C28.2, C29.2, C30.2, J5.1, J5.5, J5.9, J5.11, J5.13, J5.15, JP5.1, OLED5.1, OLED5.7, OLED5.9, OLED5.10, OLED5.27, OLED5.28, R33.1, S13.B2, S14.B2, S15.GND
GND5: C31.2, C34.2, C35.2, C36.2, J6.1, J6.5, J6.9, J6.11, J6.13, J6.15, JP6.1, OLED6.1, OLED6.7, OLED6.9, OLED6.10, OLED6.27, OLED6.28, R41.1, S16.B2, S17.B2, S18.GND
GND6: C37.2, C40.2, C41.2, C42.2, J7.1, J7.5, J7.9, J7.11, J7.13, J7.15, JP7.1, OLED7.1, OLED7.7, OLED7.9, OLED7.10, OLED7.27, OLED7.28, R49.1, S19.B2, S20.B2, S21.GND
GND7: C43.2, C46.2, C47.2, C48.2, J8.1, J8.5, J8.9, J8.11, J8.13, J8.15, JP8.1, OLED8.1, OLED8.7, OLED8.9, OLED8.10, OLED8.27, OLED8.28, R57.1, S22.B2, S23.B2, S24.GND
GND8: C49.2, C52.2, C53.2, C54.2, J9.1, J9.5, J9.9, J9.11, J9.13, J9.15, JP9.1, OLED9.1, OLED9.7, OLED9.9, OLED9.10, OLED9.27, OLED9.28, R65.1, S25.B2, S26.B2, S27.GND
GND9: C55.2, C58.2, C59.2, C60.2, J10.1, J10.5, J10.9, J10.11, J10.13, J10.15, JP10.1, OLED10.1, OLED10.7, OLED10.9, OLED10.10, OLED10.27, OLED10.28, R73.1, S28.B2, S29.B2, S30.GND
GND10: C61.2, C64.2, C65.2, C66.2, J11.1, J11.5, J11.9, J11.11, J11.13, J11.15, JP11.1, OLED11.1, OLED11.7, OLED11.9, OLED11.10, OLED11.27, OLED11.28, R81.1, S31.B2, S32.B2, S33.GND
GND11: C67.2, C70.2, C71.2, C72.2, J12.1, J12.5, J12.9, J12.11, J12.13, J12.15, JP12.1, OLED12.1, OLED12.7, OLED12.9, OLED12.10, OLED12.27, OLED12.28, R89.1, S34.B2, S35.B2, S36.GND
GND12: C73.2, C76.2, C77.2, C78.2, J13.1, J13.5, J13.9, J13.11, J13.13, J13.15, JP13.1, OLED13.1, OLED13.7, OLED13.9, OLED13.10, OLED13.27, OLED13.28, R97.1, S37.B2, S38.B2, S39.GND
GND13: C79.2, C82.2, C83.2, C84.2, J14.1, J14.5, J14.9, J14.11, J14.13, J14.15, JP14.1, OLED14.1, OLED14.7, OLED14.9, OLED14.10, OLED14.27, OLED14.28, R105.1, S40.B2, S41.B2, S42.GND
GND14: C85.2, C88.2, C89.2, C90.2, J15.1, J15.5, J15.9, J15.11, J15.13, J15.15, JP15.1, OLED15.1, OLED15.7, OLED15.9, OLED15.10, OLED15.27, OLED15.28, R113.1, S43.B2, S44.B2, S45.GND
GND15: C91.2, C94.2, C95.2, C96.2, J16.1, J16.5, J16.9, J16.11, J16.13, J16.15, JP16.1, OLED16.1, OLED16.7, OLED16.9, OLED16.10, OLED16.27, OLED16.28, R121.1, S46.B2, S47.B2, S48.GND
GND16: C97.2, C100.2, C101.2, C102.2, J17.1, J17.5, J17.9, J17.11, J17.13, J17.15, JP17.1, OLED17.1, OLED17.7, OLED17.9, OLED17.10, OLED17.27, OLED17.28, R129.1, S49.B2, S50.B2, S51.GND
GND17: C103.2, C106.2, C107.2, C108.2, J18.1, J18.5, J18.9, J18.11, J18.13, J18.15, JP18.1, OLED18.1, OLED18.7, OLED18.9, OLED18.10, OLED18.27, OLED18.28, R137.1, S52.B2, S53.B2, S54.GND
GND18: C109.2, C112.2, C113.2, C114.2, J19.1, J19.5, J19.9, J19.11, J19.13, J19.15, JP19.1, OLED19.1, OLED19.7, OLED19.9, OLED19.10, OLED19.27, OLED19.28, R145.1, S55.B2, S56.B2, S57.GND
GND19: C115.2, C118.2, C119.2, C120.2, J20.1, J20.5, J20.9, J20.11, J20.13, J20.15, JP20.1, OLED20.1, OLED20.7, OLED20.9, OLED20.10, OLED20.27, OLED20.28, R153.1, S58.B2, S59.B2, S60.GND
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

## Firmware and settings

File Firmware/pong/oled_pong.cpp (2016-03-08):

/******************************************************************************
* pong.cpp
* Play a game of pong on the Edison OLED Block!
* Jim Lindblom @ SparkFun Electronics
* Original Creation Date: January 8, 2014
*
* This sketch uses the Edison OLED library to draw a 3-D projected
* cube, and rotate it along all three axes.
*
* This code is beerware; if you see me (or any other SparkFun employee) at the
* local, and you've found our code helpful, please buy us a round!
*
* Distributed as-is; no warranty is given.
******************************************************************************/

#include <iostream>
#include "oled/Edison_OLED.h"
#include "gpio/gpio.h"
#include "math.h"
#include <unistd.h> // for usleep
#include <stdlib.h> // Gives us atoi
#include <stdio.h>

using namespace std;

// Function prototypes:
void setupOLED();
void startScreen();
void updatePaddlePositions();
float constrainPosition(float position);
void moveBall();
void drawGame();
void drawScore(int player1, int player2);
void drawPaddle(int x, int y);
void drawBall(int x, int y);
int checkWin();
void drawWin(int player);
void cleanUp();

// Define an edOLED object:
edOLED oled;

// Pin definitions:
// All buttons have pull-up resistors on-board, so just declare
// them as regular INPUT's
gpio BUTTON_UP(47, INPUT);
gpio BUTTON_DOWN(44, INPUT);
gpio BUTTON_LEFT(165, INPUT);
gpio BUTTON_RIGHT(45, INPUT);
gpio BUTTON_SELECT(48, INPUT);
gpio BUTTON_A(49, INPUT);
gpio BUTTON_B(46, INPUT);

// Game Variables:
int scoreToWin = 10;
int playerScore = 0;
int player2Score = 0;

const float paddleWidth = LCDWIDTH/16.0;
const float paddleHeight = LCDHEIGHT/3.0;
const float halfPaddleWidth = paddleWidth/2.0;
const float halfPaddleHeight = paddleHeight/2.0;

float player1PosX = 1.0 + halfPaddleWidth;
float player1PosY = 0.0;
float player2PosX = LCDWIDTH - 1.0 - halfPaddleWidth;
float player2PosY = 0.0;
float enemyVelY = 0.5;

const float ballRadius = 2.0;
const float ballSpeedX = 1.0;
float ballPosX = LCDWIDTH/2.0;
float ballPosY = LCDHEIGHT/2.0;
float ballVelX = -1.0 * ballSpeedX;
float ballVelY = 0;

enum {
	PLAYER_1_WIN = 1,
	PLAYER_2_WIN = 2
};
enum {
	SINGLE_PLAYER,
	MULTI_PLAYER
};
int playMode = SINGLE_PLAYER;

int main(int argc, char * argv[])
{
	if (argc == 2)
	{
		scoreToWin = atoi(argv[1]);
	}
	printf("Playing to %d\r\n", scoreToWin);

	setupOLED();
	startScreen();

	while (1)
	{
		updatePaddlePositions();
		moveBall();
		drawGame();
		if (checkWin())
		{
			drawWin(checkWin());
			cleanUp();
			return 0;
		}
	}
}

void setupOLED()
{
	oled.begin();
	oled.clear(PAGE);
	oled.display();
	oled.setFontType(0);
}

void startScreen()
{
	// Reset all game variables:
	player2Score = 0;
	playerScore = 0;
	player2PosY = 0.0;
	ballPosX = LCDWIDTH/2.0;
	ballPosY = LCDHEIGHT/2.0;
	ballVelX = -1.0 * ballSpeedX;
	ballVelY = 0.0;

	// Draw the splash screen:
	oled.clear(PAGE);
	oled.setCursor(14, 5);
	oled.print("Press A");
	oled.setCursor(2, 13);
	oled.print("for single");
	oled.setCursor(14, 30);
	oled.print("Press B");
	oled.setCursor(6, 38);
	oled.print("for multi");
	// Call display to actually draw it on the OLED:
	oled.display();

	// Wait for either button A or B to be pressed:
	while ((BUTTON_A.pinRead() == HIGH) && (BUTTON_B.pinRead() == HIGH))
		;
	// If button A is pressed, play single player
	if (BUTTON_A.pinRead() == LOW)
		playMode = SINGLE_PLAYER;
	// If button B is pressed, play mutli-player
	else if (BUTTON_B.pinRead() == LOW)
		playMode = MULTI_PLAYER;
}

// Update the positions of the paddles:
void updatePaddlePositions()
{
	// Update player 1's paddle:
	if (BUTTON_UP.pinRead() == LOW)
	{
		player1PosY--;
	}
	if (BUTTON_DOWN.pinRead() == LOW)
	{
		player1PosY++;
	}
	player1PosY = constrainPosition(player1PosY);

	// Move player 2 paddle:
	if (playMode == SINGLE_PLAYER)
	{
		// Update AI's paddle:
		// Follow along with the ball's position:
		if (player2PosY < ballPosY)
		{
			player2PosY += enemyVelY;
		}
		else if(player2PosY > ballPosY)
		{
			player2PosY -= enemyVelY;
		}
	}
	else if (playMode == MULTI_PLAYER)
	{
		if (BUTTON_A.pinRead() == LOW)
		{
			player2PosY--;
		}
		if (BUTTON_B.pinRead() == LOW)
		{
			player2PosY++;
		}
	}
	player2PosY = constrainPosition(player2PosY);
}

// Constrain a paddle's position to within the display's border
float constrainPosition(float position)
{
	float newPaddlePosY = position;

	if (position - halfPaddleHeight < 0)
	{
		newPaddlePosY = halfPaddleHeight;
	}
	else if (position + halfPaddleHeight > LCDHEIGHT)
	{
		newPaddlePosY = LCDHEIGHT - halfPaddleHeight;
	}

	return newPaddlePosY;
}

// Move the ball and re-calculate its position:
void moveBall()
{
	ballPosY += ballVelY;
	ballPosX += ballVelX;

	// Top and bottom wall collisions
	if (ballPosY < ballRadius)
	{
		ballPosY = ballRadius;
		ballVelY *= -1.0;
	}
	else if (ballPosY > LCDHEIGHT - ballRadius)
	{
		ballPosY = LCDHEIGHT - ballRadius;
		ballVelY *= -1.0;
	}

	// Left and right wall collisions
	if (ballPosX < ballRadius)
	{
		ballPosX = ballRadius;
		ballVelX = ballSpeedX;
		player2Score++;
	}
	else if (ballPosX > LCDWIDTH - ballRadius)
	{
		ballPosX = LCDWIDTH - ballRadius;
		ballVelX *= -1.0 * ballSpeedX;
		playerScore++;
	}

	// Paddle collisions
	if (ballPosX < player1PosX + ballRadius + halfPaddleWidth)
	{
		if (ballPosY > player1PosY - halfPaddleHeight - ballRadius &&
				ballPosY < player1PosY + halfPaddleHeight + ballRadius)
		{
			ballVelX = ballSpeedX;
			ballVelY = 2.0 * (ballPosY - player1PosY) / halfPaddleHeight;
		}
	}
	else if (ballPosX > player2PosX - ballRadius - halfPaddleWidth)
	{
		if (ballPosY > player2PosY - halfPaddleHeight - ballRadius &&
				ballPosY < player2PosY + halfPaddleHeight + ballRadius)
		{
			ballVelX = -1.0 * ballSpeedX;
			ballVelY = 2.0 * (ballPosY - player2PosY) / halfPaddleHeight;
		}
	}
}

// Draw the paddles, ball and score:
void drawGame()
{
	oled.clear(PAGE);

	drawScore(playerScore, player2Score);
	drawPaddle(player1PosX, player1PosY);
	drawPaddle(player2PosX, player2PosY);
	drawBall(ballPosX, ballPosY);

	oled.display();
}

// Draw the two score integers on the screen
void drawScore(int player1, int player2)
{
	oled.setCursor(10, 2);
	oled.print(player1);
	oled.setCursor(50, 2);
	oled.print(player2);
}

// Draw a paddle, given it's x and y coord's
void drawPaddle(int x, int y)
{
	oled.rect(x - halfPaddleWidth,
			y - halfPaddleHeight,
			paddleWidth,
			paddleHeight);
}

// Draw a ball, give it's x and y coords
void drawBall(int x, int y)
{
	oled.circle(x, y, 2);
}

// Check if either player has won.
// Returns:
//	0 - Neither player has won.
//  1 - Player 1 has won
//  2 - Player 2 has won
int checkWin()
{
	if (playerScore >= scoreToWin)
	{
		return PLAYER_1_WIN;
	}
	else if (player2Score >= scoreToWin)
	{
		return PLAYER_2_WIN;
	}

	return 0;
}

// Draw the win screen.
// Keep it up for 5 seconds.
// Then go back to the splash screen.
void drawWin(int player)
{
	oled.setCursor(10, 2);
	oled.clear(PAGE);
	if (player == PLAYER_1_WIN)
	{
		oled.print("Player 1");
	}
	else if (player == PLAYER_2_WIN)
	{
		oled.print("Player 2");
	}
	oled.setCursor(20, 12);
	oled.print("Wins!");
	oled.display();

	usleep(5000000);
}

void cleanUp()
{
	oled.clear(PAGE);
	oled.display();
}

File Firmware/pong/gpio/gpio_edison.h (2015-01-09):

#ifndef __gpio_edison_h__
#define __gpio_edison_h__

// gpioHelper is defined independently in a platform-specific file, and
//  abstracts the nitty-gritty details of how a GPIO pin is actually accessed
//  for a given platform. Sometimes it'll be via file descriptors, other 
//  times, it'll be via register access.

// In the Edison, GPIO pins can be multiplexed to different functions. While 
//  *can* access them via the /sys/class/gpio route, it's more useful (although
//  more verbose) to go through /sys/kernel/debug/gpio_debug.

// One of the main reasons for using the debug route is that the Edison has some
//  internal muxing going on that you need to adjust to enable alternate
//  functions on the GPIO pins (things like PWM and SPI, for instance).

// This directory contains *all* valid native GPIO pins. Pins provided via the 
//  I/O expanders are not in this folder, however; to access them, you'll need
//  to go through the /sys/class/gpio/ interface.
#define GPIO_ROOT "/sys/kernel/debug/gpio_debug/"

// Each GPIO has a directory associated with it. Each directory has a number of 
//  super useful files inside. These strings link to those files.

// This file is read/write for current value of the pin. Write a string of "low"
//  or "high" to it, or read it to get "low" or "high" back.
#define GPIO_VALUE GPIO_ROOT "gpio%u/current_value"

// Current pin direction. This is *only* for input/output mode: more advanced 
//  modes, like I2C et al, are set via the next file, current_pinmux.
#define GPIO_DIRECTION GPIO_ROOT "gpio%u/current_direction"

// Current pin mux mode. There are, generally, 8 modes, denoted by strings
//  "mode0", etc. "mode0" indicates GPIO mode; others are something else and
//  we'll cover that in appropriate places.
#define GPIO_MODE GPIO_ROOT "gpio%u/current_pinmux"

// If we want to have a pullup or pulldown on the pin, we need to write
//  "pullup" or "pulldown" to this file.
#define GPIO_PULLMODE GPIO_ROOT "gpio%u/current_pullmode"

class gpioHelper
{
  friend class gpio;
  private:
    int _valueFileID;
    int _modeFileID;
    int _dirFileID;
    int _pullmodeFileID;
    void writeFile(int fileID, const char *value);
};

#endif

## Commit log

2014-08-06 Initial commit of hardware (v01)
    [edison_mezzanine_oled.brd, edison_mezzanine_oled.sch]
2014-08-06 Removing top-side mezzanine connector
    Rerouting, increasing minimum trace width to 8mil, upping via drills to
    20mil.
    [edison_mezzanine_oled.brd, edison_mezzanine_oled.sch]
2014-08-07 Moving OLED passives to top side
    [edison_mezzanine_oled.brd]
2014-08-08 Moving screen closer towards middle of board
    - Updating Edison package
    - Moving Joystick and buttons towards middle of board.
    [edison_mezzanine_oled.brd, edison_mezzanine_oled.sch]
2014-08-11 adding fiducials to bottom side
    [edison_mezzanine_oled.brd, edison_mezzanine_oled.sch]
2014-08-12 renaming the board
    [edison_mezzanine_oled.brd]
2014-08-12 further genericizing the name
    [edison_mezzanine_oled.brd]
2014-09-18 adding pull-up resistors to inputs. v02
    [oled_block.brd, oled_block.sch]
2014-09-19 updated SCH edison symbol with new version, moved name to bottom corner of keepout.
    [oled_block.brd, oled_block.sch]
2014-09-23 cleaned up pours, added isolate
    [oled_block.brd]
2014-09-25 file cleanup
    [oled_block.sch]
2014-10-16 cleaning up some silk (v10)
    [oled_block.brd, oled_block.sch]
2014-10-17 Fixing button package. Silk fixes
    [oled_block.brd, oled_block.sch]
2014-10-17 updating connector package
    [oled_block.brd, oled_block.sch]
2014-10-17 adjusting a few traces
    [oled_block.brd]
2014-10-17 Ready for reds Added VSYS header No known to-do items
    [oled_block.brd, oled_block.sch]
2014-10-23 created v10 panels
    [OLED_Block-GiantPanel-v10.brd, OLED_Block-Panel-v10.brd]
2015-04-01 Updating README and directory file names
    [OLED_Block-GiantPanel-v10.brd, OLED_Block-Panel-v10.brd]
2015-11-20 Update Edison_OLED.h
    Added prototype for printing floats
2015-11-20 Update Edison_OLED.cpp
    Added function for printing floats. Floats are rounded to 2 decimal places
2016-02-15 Changed macro "swap" to "swapOLED"
    I found that using the macro name "swap" would interfere with system libraries, such as sstream and regex
    [Edison_OLED.cpp]

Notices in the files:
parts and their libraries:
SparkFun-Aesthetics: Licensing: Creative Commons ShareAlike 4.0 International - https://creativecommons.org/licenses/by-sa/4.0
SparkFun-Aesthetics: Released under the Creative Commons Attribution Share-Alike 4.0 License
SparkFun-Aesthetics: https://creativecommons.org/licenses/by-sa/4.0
